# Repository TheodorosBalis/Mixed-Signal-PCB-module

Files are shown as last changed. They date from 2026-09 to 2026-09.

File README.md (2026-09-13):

# Mixed-Signal PCB Module

A four-layer KiCad 9 PCB design for a compact GSM/GPRS handheld device. It combines a Quectel M95 cellular module, an STM32 microcontroller, battery charging and regulation, a SIM interface, display connector, keypad, and audio circuitry.

## Design specifications

| Item | Implemented design |
| --- | --- |
| Board outline | 46 x 100 mm |
| Copper layers | 4: `F.Cu`, `In1.Cu`, `In2.Cu`, `B.Cu` |
| Stackup material | FR-4 dielectrics; ENIG finish specified in KiCad |
| Board thickness | 2.9984 mm as currently stored in the PCB file; confirm with the fabricator |
| Cellular module | Quectel M95 GSM/GPRS (`U1`) |
| MCU | STM32G030K6Tx (`U2`) |
| Power | BQ24166RGE charger/power-path IC (`U4`), 3.3 V regulator (`U3`), Micro-USB power input (`J3`), battery connector (`J1`) |
| RF interface | U.FL coaxial connector (`J6`) for an external antenna; 0-ohm series link (`R5`) and DNP shunt matching positions (`C16`, `C17`) |
| Display | 12-position, 0.5 mm-pitch FPC connector (`J4`) for the intended ST7789-based 240 x 240 LCD module |
| SIM | Nano-SIM connector (`J5`) with interface protection |
| User I/O | 20 keypad switches, status LEDs, microphone, speaker |
| Programming/debug | Tag-Connect SWD connector (`J2`); SWO is not connected |
| Mechanical | Four 2 mm mounting-hole footprints |

The Micro-USB connector is used for power; its USB data pins are unconnected in this design. The U.FL connector is **not** an antenna: an appropriate external antenna and cable are required for RF operation.

## Repository files

- `mixedsignalBoard.kicad_pro` - KiCad project settings.
- `mixedsignalBoard.kicad_sch` - circuit schematic.
- `mixedsignalBoard.kicad_pcb` - PCB layout, footprints, routing, and board stackup.

Open `mixedsignalBoard.kicad_pro` with KiCad 9 to inspect the schematic and layout. Firmware, manufacturing exports, assembly files, and a physical antenna are not included in this repository.

## Before fabrication

This is a design project, not a validated hardware product. Check the actual LCD module pinout and connector orientation, antenna matching and 50-ohm RF geometry against the chosen fabricator's stackup, and all component part numbers before ordering. The PCB currently assigns both inner copper zones to `M95_SIM_GND` and records an approximately 3.0 mm stackup; verify that these are intentional and manufacturable. Passing ERC or DRC alone does not establish electrical, RF, or functional performance.

## Design gallery

The views below show the system block diagram, complete schematic, PCB routing, and both sides of the board. The 3D images are KiCad renders, not photographs of fabricated hardware.

### System block diagram

The diagram summarizes power distribution and the connections between the STM32, M95, display, keypad, SIM, RF, and audio circuits.

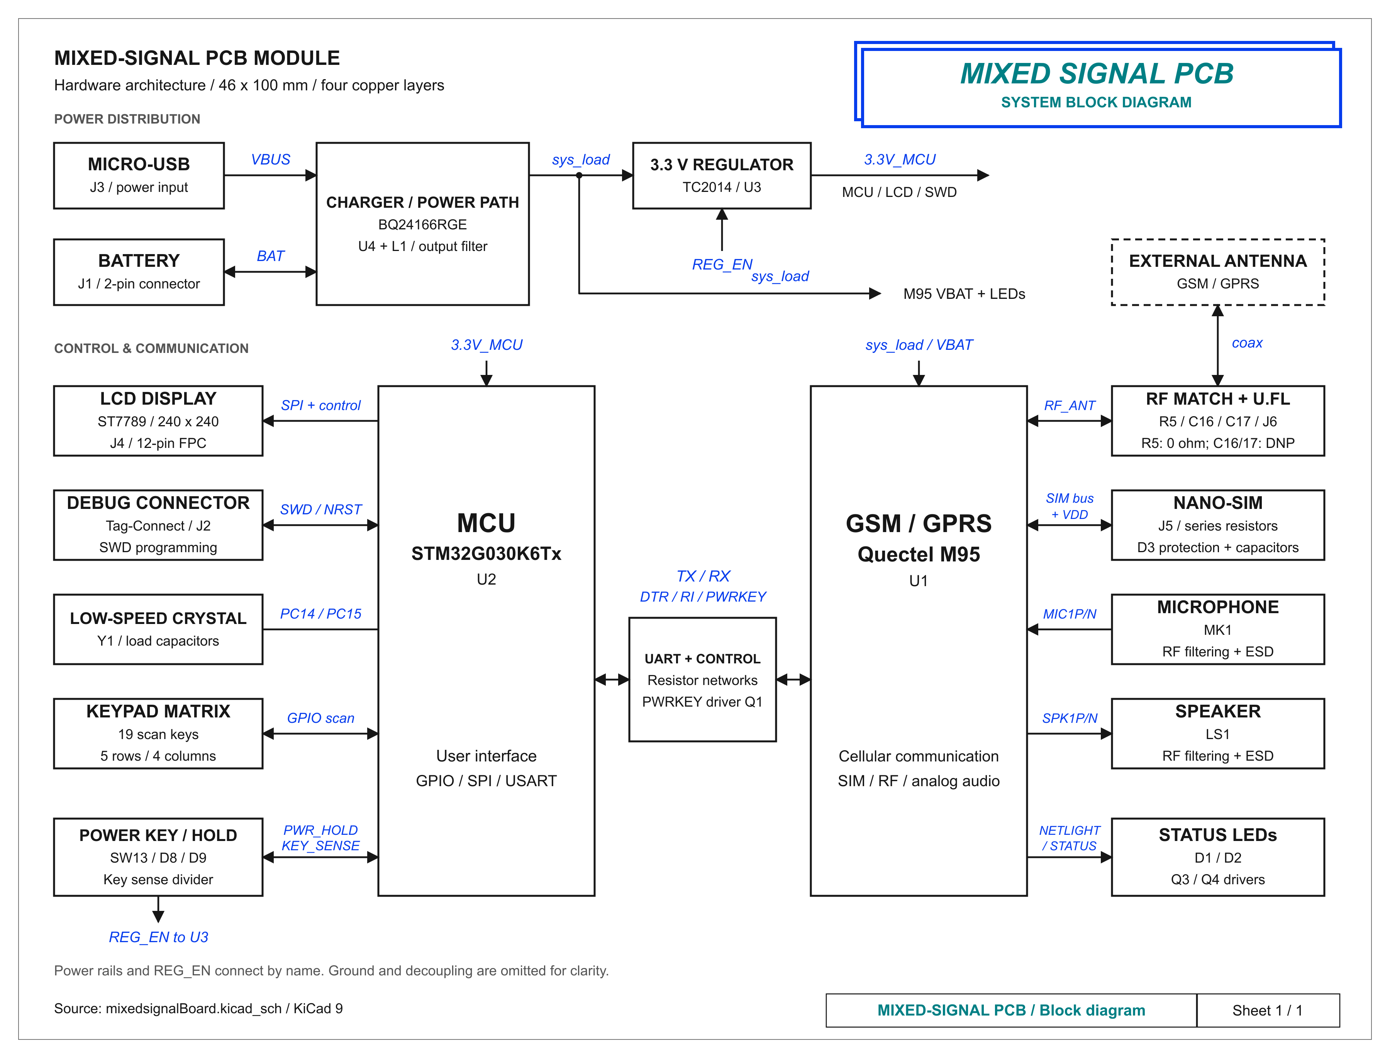
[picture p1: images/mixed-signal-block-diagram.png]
Mixed-signal PCB system block diagram


[High-resolution PNG](images/mixed-signal-block-diagram.png) | [Editable SVG](images/mixed-signal-block-diagram.svg)

### Schematic

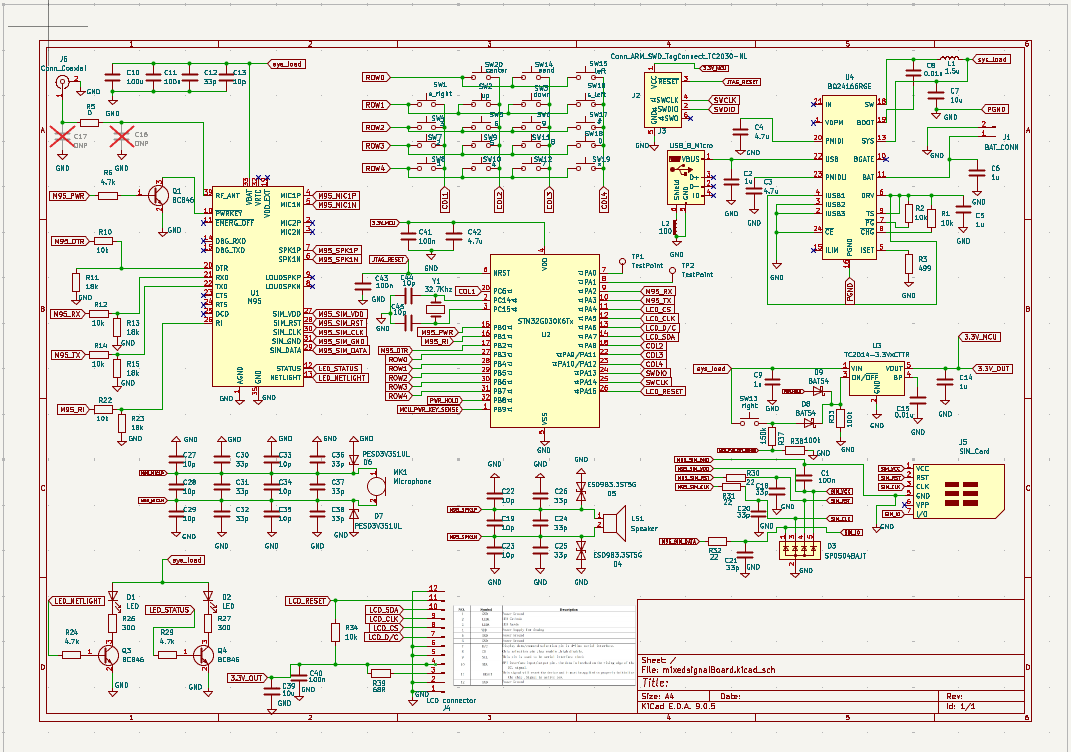
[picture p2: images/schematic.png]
Complete KiCad schematic


### PCB layout

| Front copper view | Multi-layer routing view |
| --- | --- |
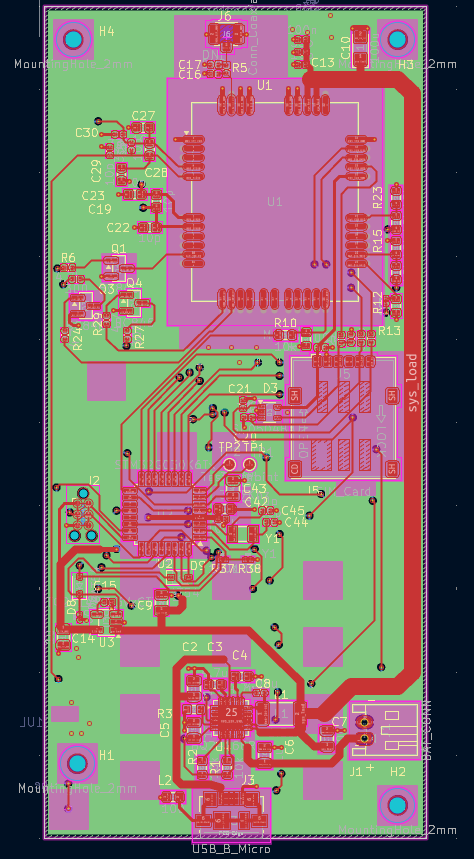
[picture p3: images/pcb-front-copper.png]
Front copper layout
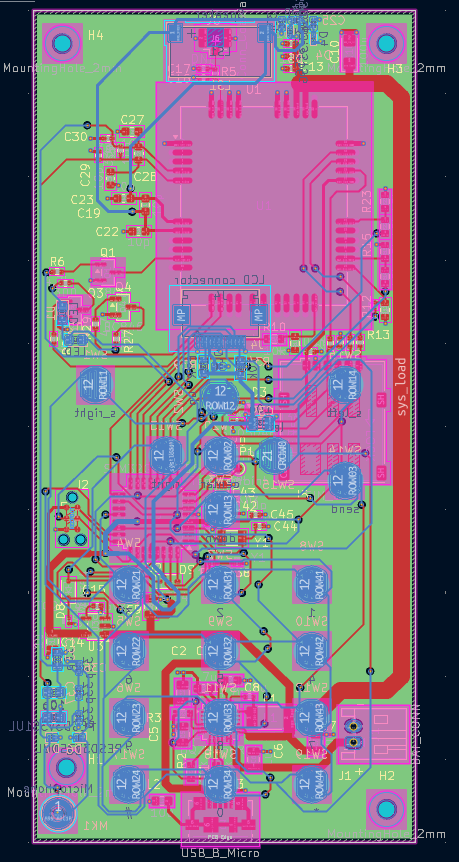
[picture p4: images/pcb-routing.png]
Multi-layer PCB routing
|  |  |

### 3D renders

| Component side | Keypad side |
| --- | --- |
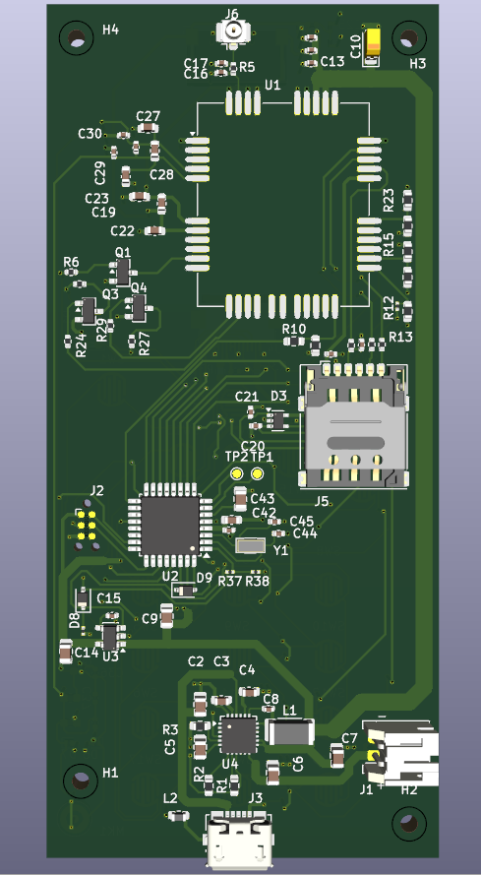
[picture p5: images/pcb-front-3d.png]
3D render of the component side
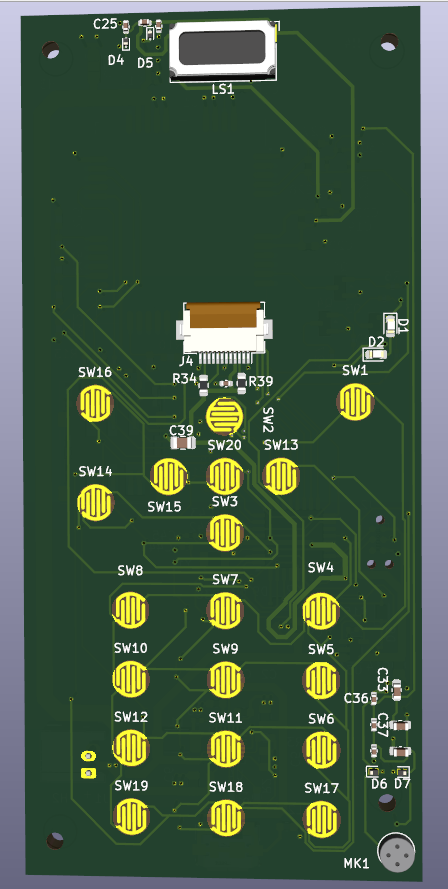
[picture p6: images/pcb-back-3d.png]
3D render of the keypad side
|  |  |

| Perspective view | Board edge profile |
| --- | --- |
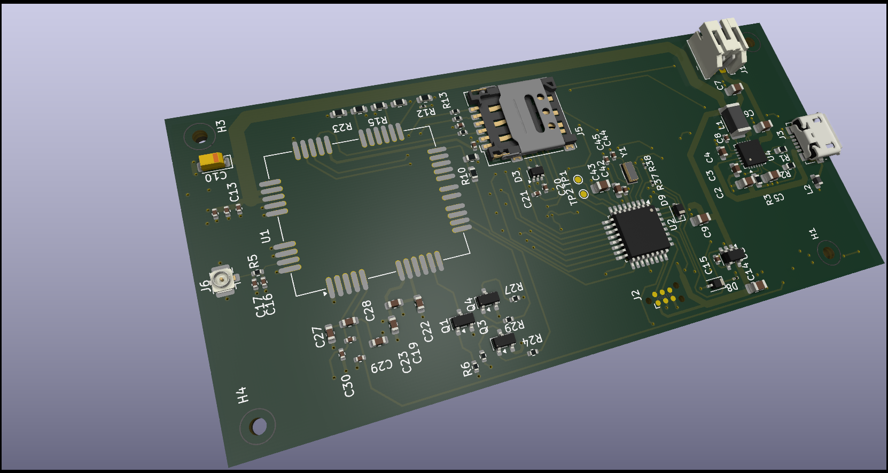
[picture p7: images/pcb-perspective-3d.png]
Perspective 3D render
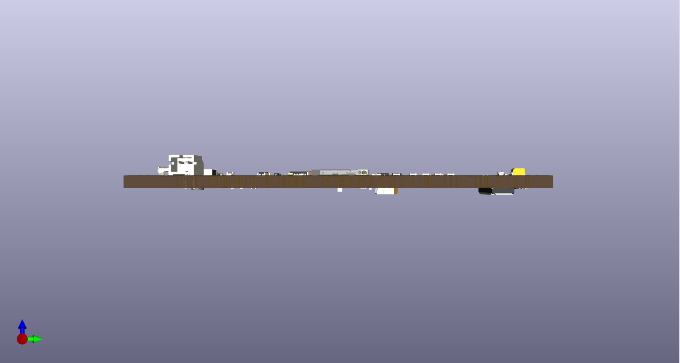
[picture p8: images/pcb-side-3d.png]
Board edge profile render
|  |  |

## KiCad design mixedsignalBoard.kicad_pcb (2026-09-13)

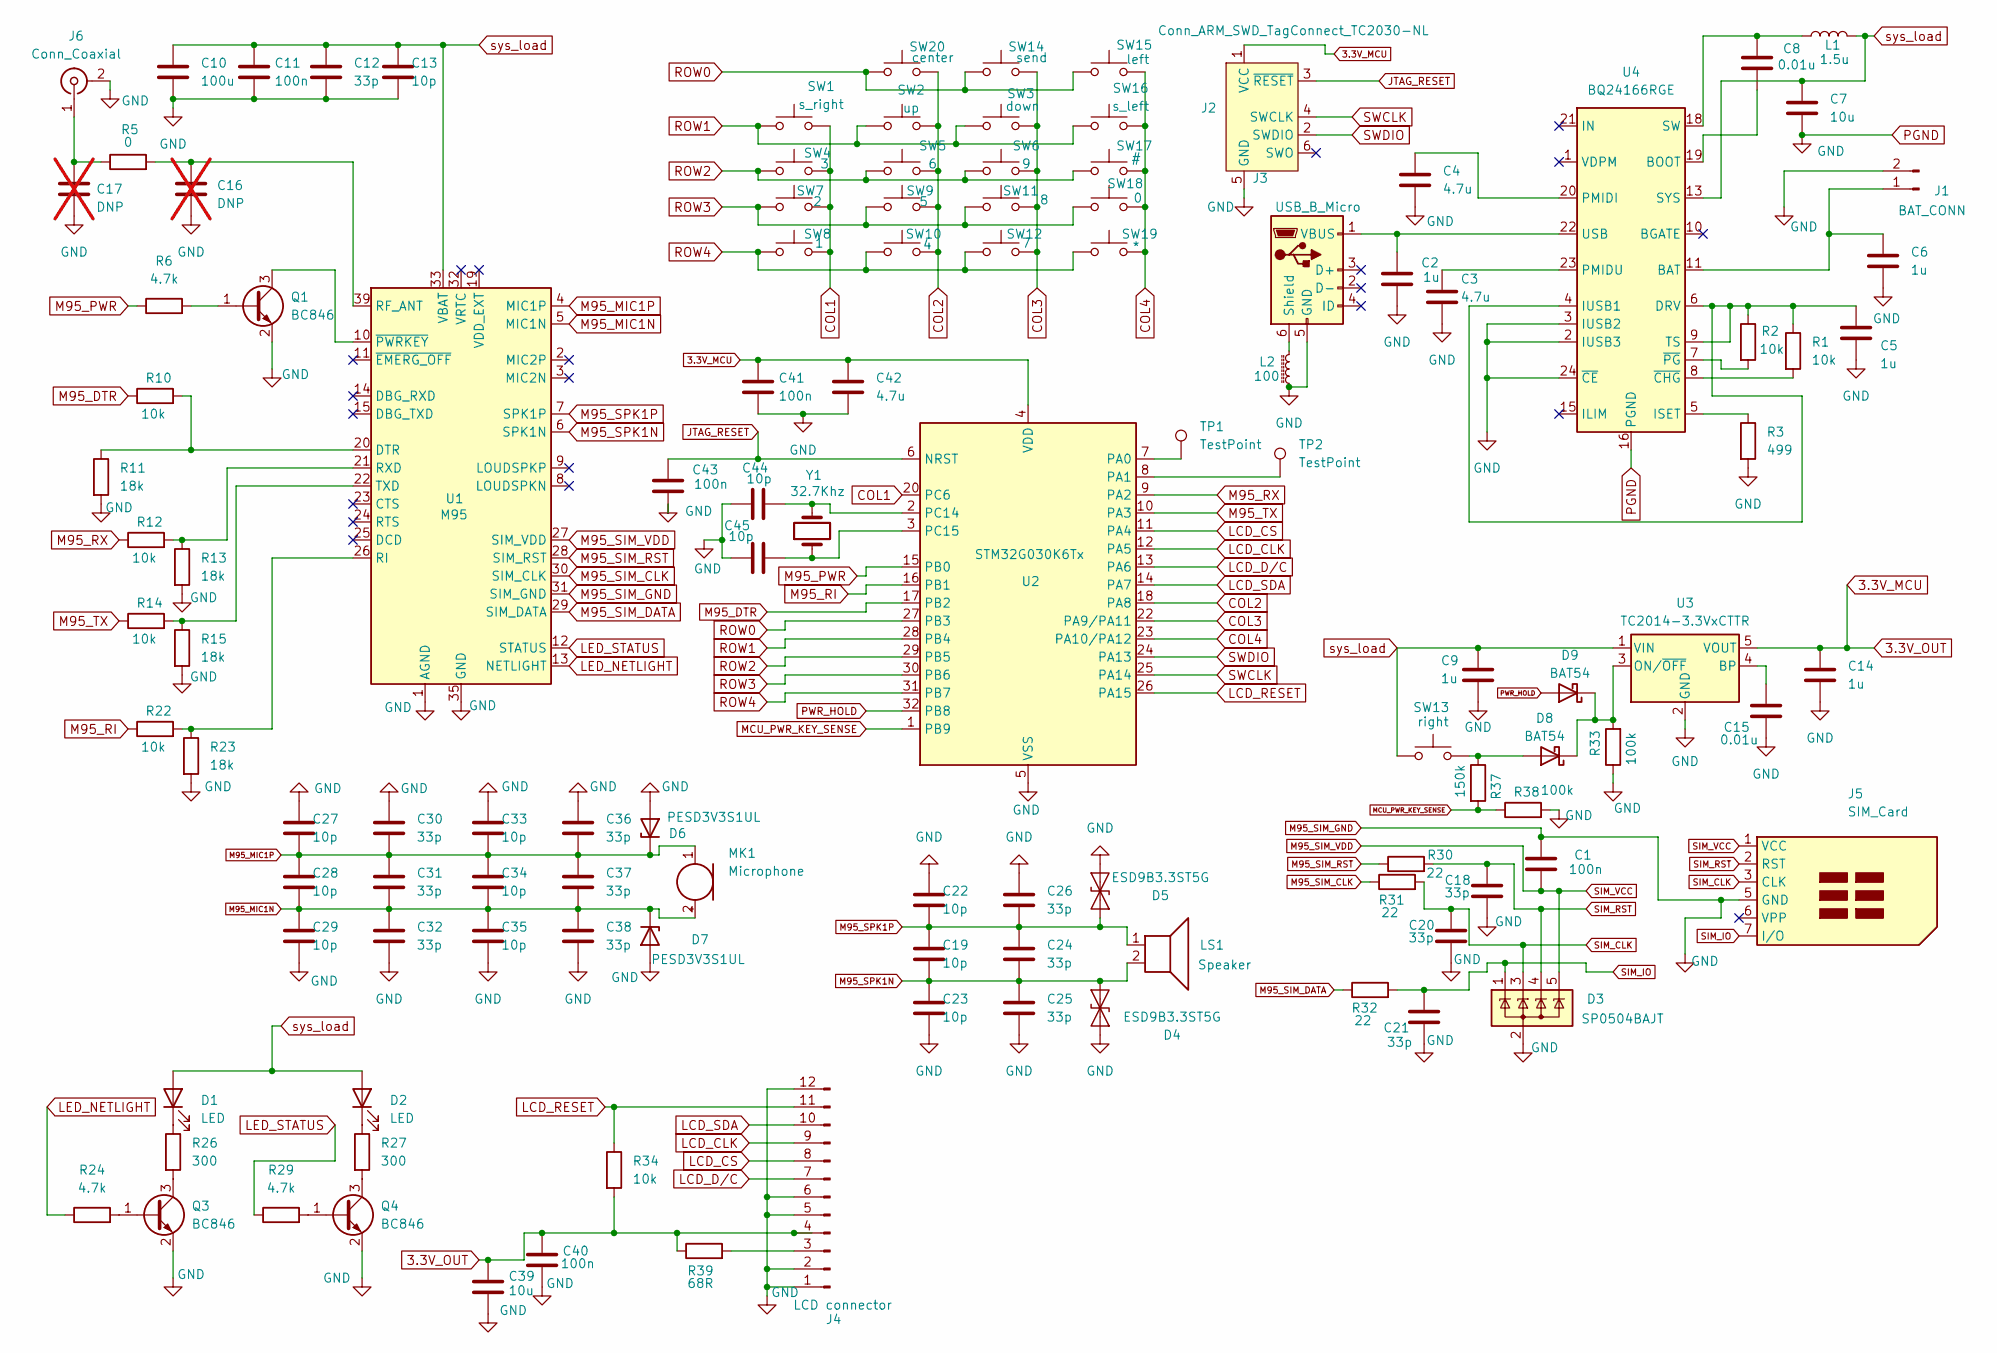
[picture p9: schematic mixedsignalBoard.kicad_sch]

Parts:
C1, C11, C40, C41: 100n; C_0402_1005Metric
C2, C5, C6, C9, C14: 1u; C_0805_2012Metric
C3, C4, C42: 4.7u; C_0603_1608Metric
C7, C39: 10u; C_0805_2012Metric
C8, C15: 0.01u; C_0402_1005Metric
C10: 100u; CP_EIA-3216-18_Kemet-A
C12, C18, C20, C21, C24, C25, C26, C30, C31, C32, C36, C37, C38: 33p; C_0402_1005Metric
C13, C44, C45: 10p; C_0402_1005Metric
C16, C17: DNP; C_0402_1005Metric; not fitted
C19, C22, C23, C27, C28, C29, C33, C34, C35: 10p; C_0603_1608Metric
C43: 100n; C_0805_2012Metric
D1, D2: LED; LED_0603_1608Metric
D3: SP0504BAJT; SOT-353_SC-70-5
D4, D5: ESD9B3.3ST5G; D_SOD-923
D6, D7: PESD3V3S1UL; D_SOD-882
D8, D9: BAT54; D_SOD-323
J1: BAT_CONN; JST_PH_S2B-PH-K_1x02_P2.00mm_Horizontal
J2: Conn_ARM_SWD_TagConnect_TC2030-NL; Tag-Connect_TC2030-IDC-NL_2x03_P1.27mm_Vertical
J3: USB_B_Micro; USB_Micro-B_Molex_47346-0001
J4: LCD connector; Hirose_FH12-12S-0.5SH_1x12-1MP_P0.50mm_Horizontal
J5: SIM_Card; nanoSIM_Hinged_CUI_NSIM-2-C
J6: Conn_Coaxial; U.FL_Hirose_U.FL-R-SMT-1_Vertical
L1: 1.5u; L_2010_5025Metric
L2: 100; L_0603_1608Metric
LS1: Speaker; Speaker_CUI_CMR-1206S-67
MK1: Microphone; CUI_CMC-4013-SMT
Q1, Q3, Q4: BC846; SOT-23
R1, R2, R10, R14, R22, R34: 10k; R_0603_1608Metric
R3: 499; R_0603_1608Metric
R5: 0; R_0402_1005Metric
R6, R24, R29: 4.7k; R_0402_1005Metric
R11, R13, R15, R23: 18k; R_0603_1608Metric
R12: 10k; R_0201_0603Metric
R26, R27: 300; R_0402_1005Metric
R30, R31, R32: 22; R_0402_1005Metric
R33, R38: 100k; R_0201_0603Metric
R37: 150k; R_0201_0603Metric
R39: 68R; R_0603_1608Metric
SW1: s_right; membrane_switch_4.4mm_V2
SW2: up; membrane_switch_4.4mm_V2
SW3: down; membrane_switch_4.4mm_V2
SW4: 3; membrane_switch_4.4mm_V2
SW5: 6; membrane_switch_4.4mm_V2
SW6: 9; membrane_switch_4.4mm_V2
SW7: 2; membrane_switch_4.4mm_V2
SW8: 1; membrane_switch_4.4mm_V2
SW9: 5; membrane_switch_4.4mm_V2
SW10: 4; membrane_switch_4.4mm_V2
SW11: 8; membrane_switch_4.4mm_V2
SW12: 7; membrane_switch_4.4mm_V2
SW13: right; membrane_switch_4.4mm_V2
SW14: send; membrane_switch_4.4mm_V2
SW15: left; membrane_switch_4.4mm_V2
SW16: s_left; membrane_switch_4.4mm_V2
SW17: #; membrane_switch_4.4mm_V2
SW18: 0; membrane_switch_4.4mm_V2
SW19: *; membrane_switch_4.4mm_V2
SW20: center; membrane_switch_4.4mm_V2
TP1, TP2: TestPoint; TestPoint_Pad_D1.0mm
U1: M95; Quectel_M95
U2: STM32G030K6Tx; LQFP-32_7x7mm_P0.8mm
U3: TC2014-3.3VxCTTR; SOT-23-5
U4: BQ24166RGE; Texas_RGE0024H_VQFN-24-1EP_4x4mm_P0.5mm_EP2.7x2.7mm
Y1: 32.7Khz; Crystal_SMD_3215-2Pin_3.2x1.5mm

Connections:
3.3V_MCU: C14.1, C39.1, C40.1, C41.1, C42.1, J2.1 (VCC), J4.4 (VDD), R34.2, R39.1, U2.4 (VDD), U3.5 (VOUT)
COL1: SW1.2, SW4.2, SW7.2, SW8.2, U2.20 (PC6)
COL2: SW2.2, SW5.2, SW9.2, SW10.2, SW20.2, U2.18 (PA8)
COL3: SW3.2, SW6.2, SW11.2, SW12.2, SW14.2, U2.22 (PA9/PA11)
COL4: SW15.2, SW16.2, SW17.2, SW18.2, SW19.2, U2.23 (PA10/PA12)
JTAG_RESET: C43.1, J2.3 (~RESET), U2.6 (NRST)
LCD_CLK: J4.9 (SCL), U2.12 (PA5)
LCD_CS: J4.8 (CS), U2.11 (PA4)
LCD_D/C: J4.7 (D/C), U2.13 (PA6)
LCD_RESET: J4.11 (RESET), R34.1, U2.26 (PA15)
LCD_SDA: J4.10 (SDA), U2.14 (PA7)
LED_NETLIGHT: R24.1, U1.13 (NETLIGHT)
LED_STATUS: R29.1, U1.12 (STATUS)
M95_DTR: R10.1, U2.17 (PB2)
M95_MIC1N: C28.2, C29.1, C31.2, C32.1, C34.2, C35.1, C37.2, C38.1, D7.1 (K), MK1.2 (+), U1.5 (MIC1N)
M95_MIC1P: C27.2, C28.1, C30.2, C31.1, C33.2, C34.1, C36.2, C37.1, D6.1 (K), MK1.1 (-), U1.4 (MIC1P)
M95_PWR: R6.1, U2.15 (PB0)
M95_RI: R22.1, U2.16 (PB1)
M95_RX: R12.1, U2.9 (PA2)
M95_SIM_CLK: R31.1, U1.30 (SIM_CLK)
M95_SIM_DATA: R32.1, U1.29 (SIM_DATA)
M95_SIM_GND: C1.1, C2.2, C3.2, C4.2, C5.2, C6.2, C7.2, C9.2, C10.2, C11.2, C12.2, C13.2, C14.2, C15.2, C16.2, C17.2, C18.2, C20.2, C21.2, C22.1, C23.2, C25.2, C26.1, C27.1, C29.2, C30.1, C32.2, C33.1, C35.2, C36.1, C38.2, C39.2, C40.2, C41.2, C42.2, C43.2, C44.1, C45.1, D3.2 (A), D4.1 (A1), D5.2 (A2), D6.2 (A), D7.2 (A), J1.2, J2.5 (GND), J3.5 (GND), J4.1 (GND), J4.2 (LEDK), J4.5 (GND), J4.6 (GND), J4.12 (GND), J5.5 (GND), J6.2 (Ext), L2.1, Q1.2 (E), Q3.2 (E), Q4.2 (E), R3.2, R11.2, R13.2, R15.2, R23.2, R33.1, R38.2, U1.1 (AGND), U1.31 (SIM_GND), U1.35 (GND), U1.36 (GND), U1.37 (GND), U1.38 (GND), U1.40 (GND), U2.5 (VSS), U3.2 (GND), U4.2 (IUSB3), U4.3 (IUSB2), U4.16 (PGND), U4.17 (PGND), U4.24 (~CE), U4.25 (PGND)
M95_SIM_RST: R30.1, U1.28 (SIM_RST)
M95_SIM_VDD: C1.2, D3.5 (K), J5.1 (VCC), U1.27 (SIM_VDD)
M95_SPK1N: C19.2, C23.1, C24.2, C25.1, D4.2 (A2), LS1.2, U1.6 (SPK1N)
M95_SPK1P: C19.1, C22.2, C24.1, C26.2, D5.1 (A1), LS1.1, U1.7 (SPK1P)
M95_TX: R14.1, U2.10 (PA3)
MCU_PWR_KEY_SENSE: R37.2, R38.1, U2.1 (PB9)
unnamed: D1.1 (K), R26.1
unnamed: D2.1 (K), R27.1
unnamed: D8.2 (A), R37.1, SW13.2
unnamed: D8.1 (K), D9.1 (K), R33.2, U3.3 (ON/~OFF)
unnamed: C6.1, J1.1, U4.11 (BAT), U4.12 (BAT)
unnamed: J3.6 (Shield), L2.2
unnamed: C2.1, J3.1 (VBUS), U4.22 (USB)
unnamed: J4.3 (LEDA), R39.2
unnamed: C17.1, J6.1 (In), R5.1
unnamed: Q1.1 (B), R6.2
unnamed: Q1.3 (C), U1.10 (~PWRKEY)
unnamed: Q3.1 (B), R24.2
unnamed: Q3.3 (C), R26.2
unnamed: Q4.1 (B), R29.2
unnamed: Q4.3 (C), R27.2
unnamed: R10.2, R11.1, U1.20 (DTR)
unnamed: C16.1, R5.2, U1.39 (RF_ANT)
unnamed: R22.2, R23.1, U1.26 (RI)
unnamed: R12.2, R13.1, U1.21 (RXD)
unnamed: R14.2, R15.1, U1.22 (TXD)
unnamed: TP1.1, U2.7 (PA0)
unnamed: TP2.1, U2.8 (PA1)
unnamed: C44.2, U2.2 (PC14), Y1.2
unnamed: C45.2, U2.3 (PC15), Y1.1
unnamed: C15.1, U3.4 (BP)
unnamed: C8.2, U4.19 (BOOT)
unnamed: C5.1, R1.1, R2.1, U4.4 (IUSB1), U4.6 (DRV), U4.9 (TS)
unnamed: R3.1, U4.5 (ISET)
unnamed: C4.1, U4.20 (PMIDI)
unnamed: C3.1, U4.23 (PMIDU)
unnamed: C8.1, L1.1, U4.18 (SW)
unnamed: R1.2, U4.8 (~CHG)
unnamed: R2.2, U4.7 (~PG)
PWR_HOLD: D9.2 (A), U2.32 (PB8)
ROW0: SW14.1, SW15.1, SW20.1, U2.27 (PB3)
ROW1: SW1.1, SW2.1, SW3.1, SW16.1, U2.28 (PB4)
ROW2: SW4.1, SW5.1, SW6.1, SW17.1, U2.29 (PB5)
ROW3: SW7.1, SW9.1, SW11.1, SW18.1, U2.30 (PB6)
ROW4: SW8.1, SW10.1, SW12.1, SW19.1, U2.31 (PB7)
SIM_CLK: C20.1, D3.3 (K), J5.3 (CLK), R31.2
SIM_IO: C21.1, D3.1 (K), J5.7 (I/O), R32.2
SIM_RST: C18.1, D3.4 (K), J5.2 (RST), R30.2
SWCLK: J2.4 (SWCLK), U2.25 (PA14)
SWDIO: J2.2 (SWDIO), U2.24 (PA13)
sys_load: C7.1, C9.1, C10.1, C11.1, C12.1, C13.1, D1.2 (A), D2.2 (A), L1.2, SW13.1, U1.33 (VBAT), U1.34 (VBAT), U3.1 (VIN), U4.13 (SYS), U4.14 (SYS)

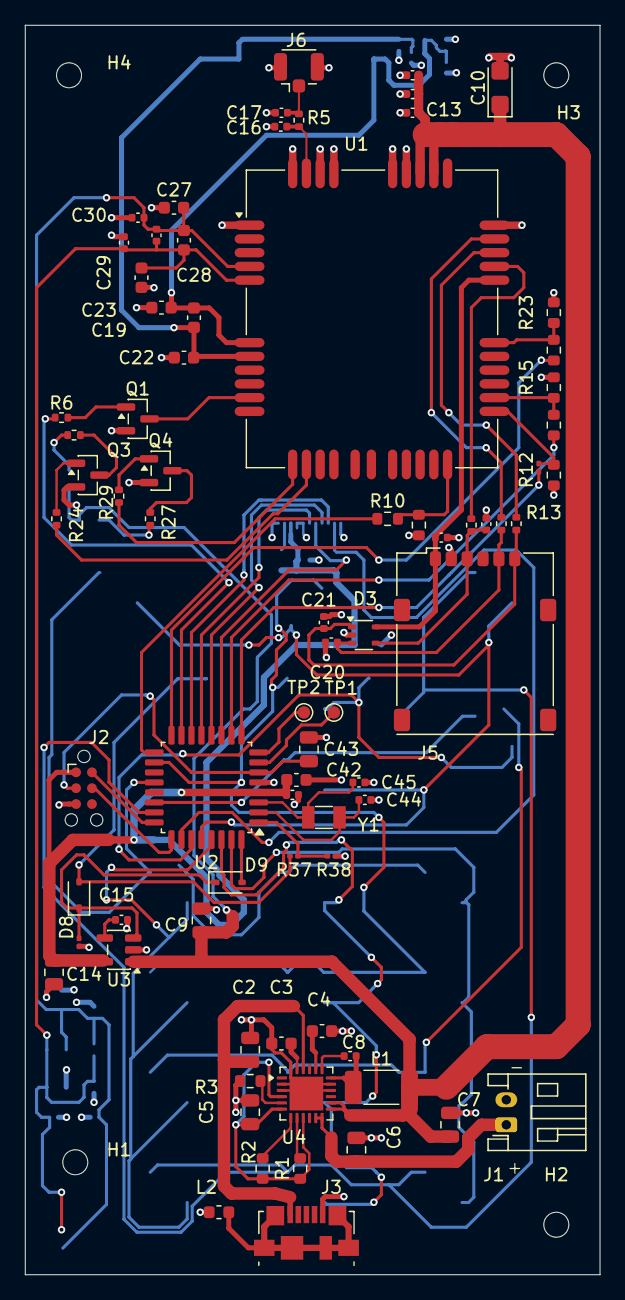
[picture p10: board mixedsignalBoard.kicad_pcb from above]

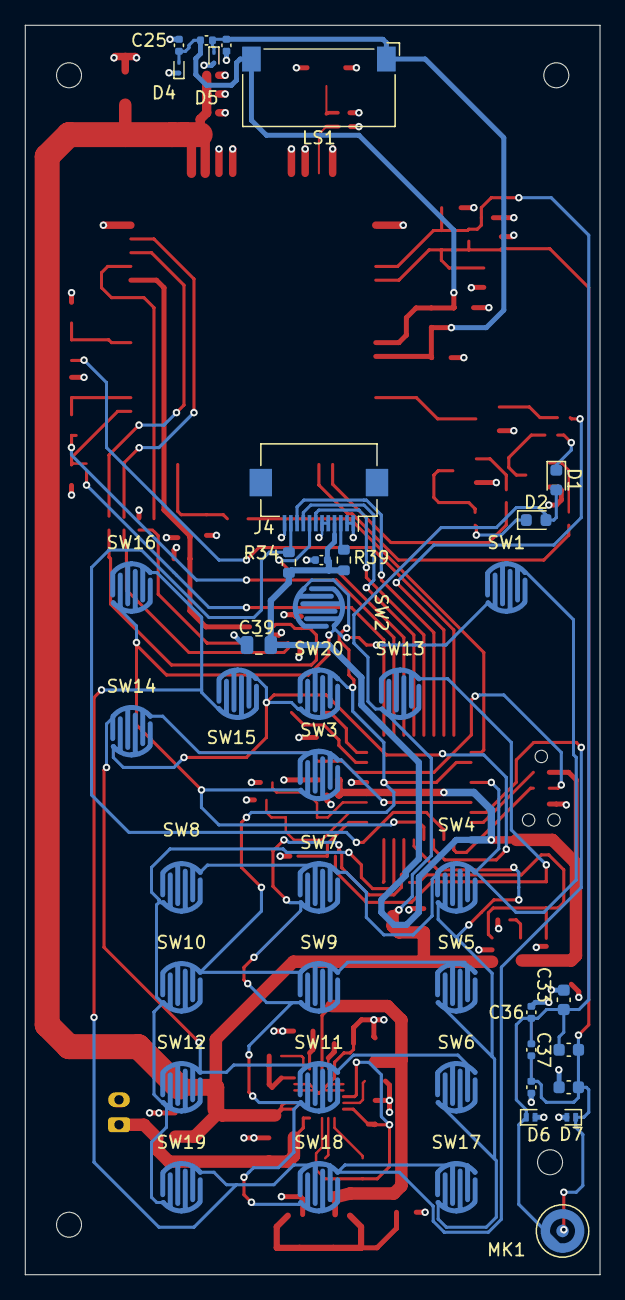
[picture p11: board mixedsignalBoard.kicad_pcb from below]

Board: 4 copper layers, 46.0 x 100.0 mm, 123 parts (42 on the bottom side), 73 nets.

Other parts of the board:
H1, H2, H3, H4: MountingHole_2mm

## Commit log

2026-09-13 Add KiCad mixed-signal PCB design
    [mixedsignalBoard.kicad_pcb, mixedsignalBoard.kicad_sch]
2026-09-13 Document PCB design specifications
2026-09-13 Add PCB design gallery to README
2026-09-13 Describe PCB design gallery
